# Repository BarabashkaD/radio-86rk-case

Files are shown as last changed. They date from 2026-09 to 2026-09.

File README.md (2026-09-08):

# radio-86rk-case

A 3D model of the [Radio-86RK](https://github.com/BarabashkaD/radio-86rk) as an
assembled machine — the populated board, its 67 keyswitches, the keycaps on top
of them, and the envelope the enclosure will be designed against.

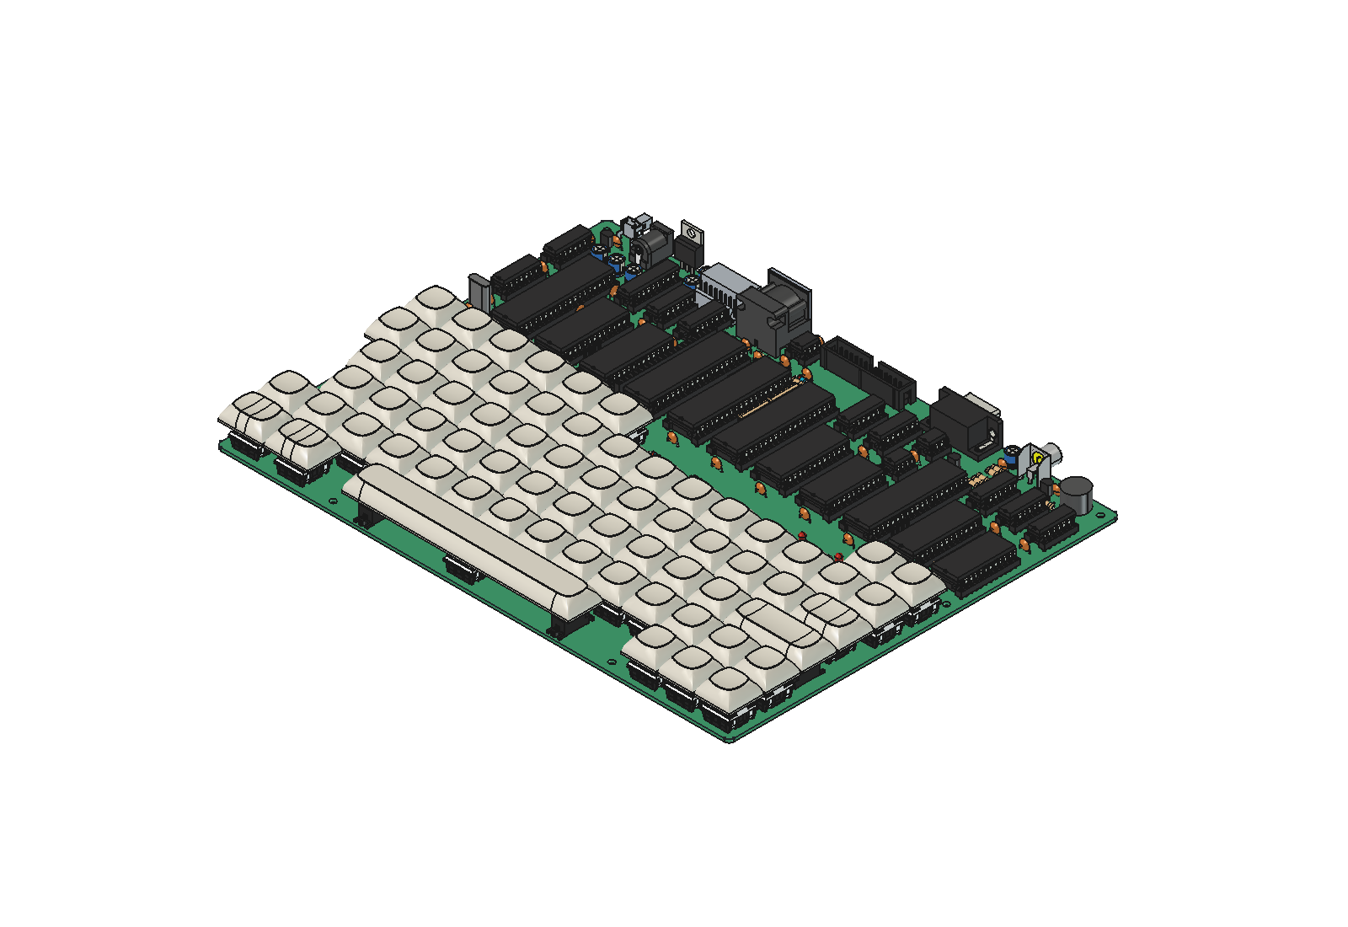
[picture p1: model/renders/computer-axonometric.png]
The assembled Radio-86RK


*The whole machine, built from tracked files in under a second. 251 components,
721 solids, 67 keycaps including the 6.25u spacebar.*

## What this repository is for

The board itself lives in a separate repository and is **read-only from here**.
This one adds everything above the PCB:

| | |
|---|---|
| **The assembled model** | `model/radio86rk-assembly.FCStd` — open it in FreeCAD and you see the machine. No build step, no scripts. |
| **The enclosure interface** | `model/envelope.step` — 67 prisms, one per key, sized to the tallest cap. Everything a case needs *for the keyboard field*; see below for what it does not carry. |
| **The keycaps** | Placed on their switches to a measured seat height, not an estimated one. |
| **A gate that checks all of it** | Eleven checks, from "does the board still have 67 switches" to "do the caps sit where they should". |

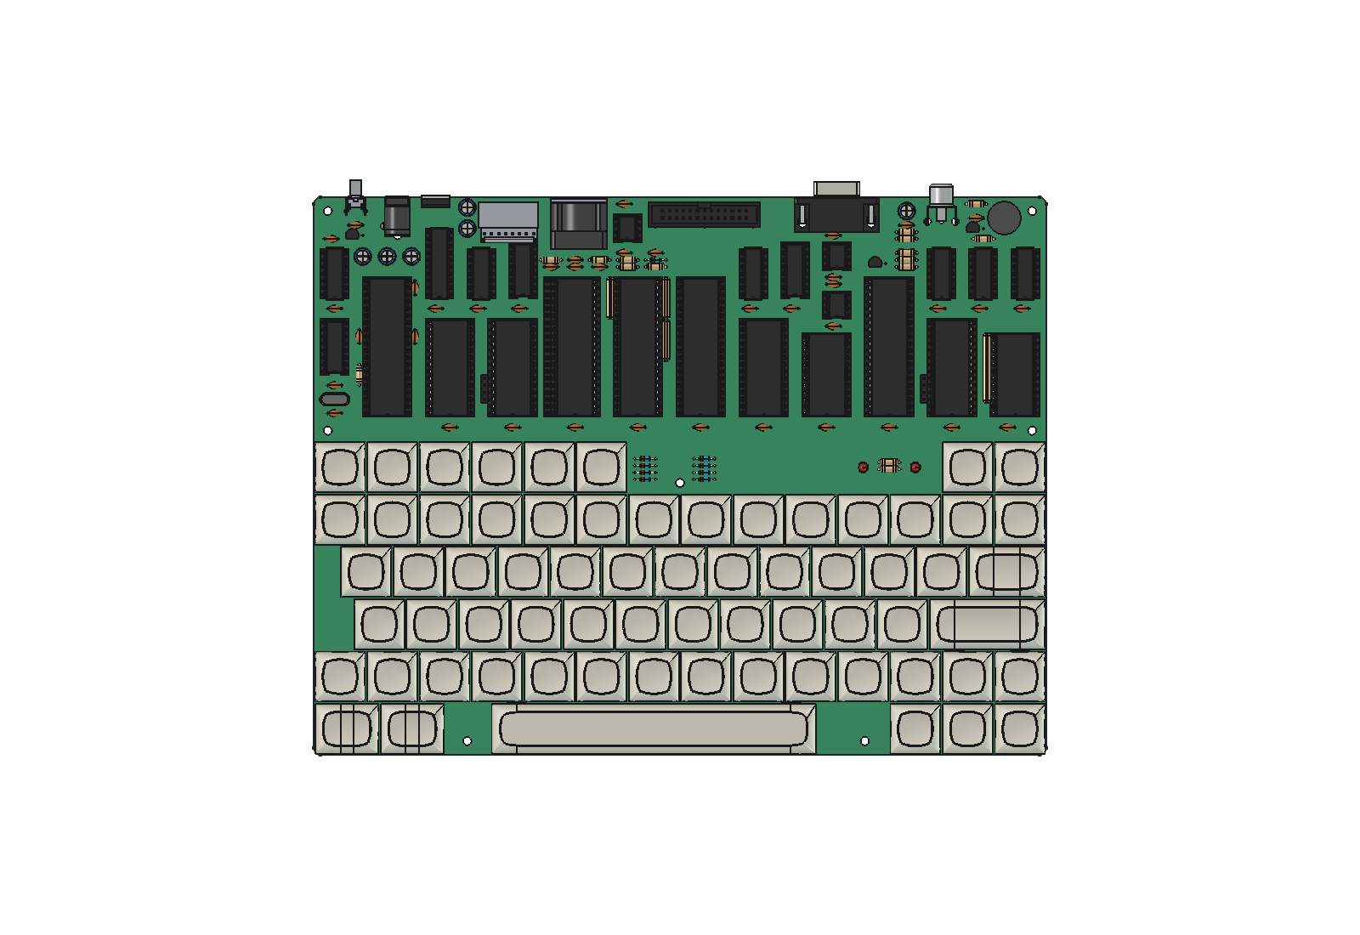
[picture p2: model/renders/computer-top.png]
Top view


## Just looking at it

Open `model/radio86rk-assembly.FCStd` in FreeCAD 1.1.1. That is the whole
instruction. The project is tracked complete — board, components, switches and
caps — so nothing needs building or generating first.

You will get the view above. Both the camera and the visibility state are saved
in the file: construction geometry is hidden, so no grey datum planes obscure
the model, and the stored camera is the isometric the render was shot from.

## Building and checking

Everything runs under FreeCAD's console binary, which is **not on `PATH`**:

    FC=/Applications/FreeCAD.app/Contents/Resources/bin/freecadcmd

    $FC tools/build_caps.py    # place the caps, write model/envelope.step   ~1 s
    $FC tools/verify.py        # the gate: 11 checks                        ~24 s

**In that order.** Four of the eleven checks read what `build_caps.py` writes,
so running the gate on a fresh clone reports `INCOMPLETE` and exit 2 — not
because anything is wrong, but because there is nothing yet to check. Build
first.

Exit codes: `0` pass, `1` a real finding, `2` could not run — never a verdict.
Both always print a `verdict:` line, so you can parse for it. Run one check with
`$FC tools/verify.py C`, or all with no argument.

`build_caps.py` writes `model/envelope.step`, which is tracked. STEP stamps a
timestamp into its header, so `git status` will report it modified after a
rebuild that changed no geometry at all. That is expected — don't commit it
unless the geometry really moved, and `$FC tools/verify.py C D` will tell you
whether it did.

## Designing a case against the envelope

`model/envelope.step` is a compound of exactly **67 rectangular prisms and
nothing else** — 402 planar faces, no board, no fasteners, no annotation. It is
the volume the keys sweep, and it is deliberately that and only that.

It is in **the board's coordinate frame**, which the STEP file itself cannot
tell you, so it is written here:

| | |
|---|---|
| Extent | X `6.675 … 272.725`, Y `−209.225 … −95.575` (266.050 × 113.650 mm) |
| Z | `10.743` (cap base) to `22.743` (cap top), uniform across all 67 |
| Key gap | 0.65 mm — each prism is that much narrower than the 19.05 mm pitch, so neighbours never touch |
| Origin | the board's, shared with `model/radio86rk-assembly.FCStd`. Load both and they line up with no transform |

**What you can design from this file alone**, confirmed by building a plate with
a keyboard cutout against it: the opening outline, the height the case must
clear, the per-key bezel if you want one, and the clearance between keys.

**What it does not carry, and where to get it:** the board outline, mounting
holes, and connector positions are not in here and cannot be derived from it.
Those come from the board — either `model/radio86rk-assembly.FCStd`, which is
in the same frame, or the KiCad project in the `radio-86rk` repository.

One thing is not encoded at all: **key travel**. The Z range is the static
worst case with the caps at rest, not the stroke. If a design needs to clear a
pressed key, that number is a Cherry MX specification, not something this
repository measures.

## Changing the keycaps

The rendered caps and the caps you buy need not match. The envelope is sized
for a sculpted Cherry/OEM profile, so a blank DSA/XDA set or a printed Cyrillic
set will both fit under it.

Swapping the *rendered* profile takes four steps today:

1. Put the new STEP files in `vendor/<profile>/`, one per key size.
2. Point `keycaps.tsv`'s `model_file` column at them — one row per size:
   1u, 1.25u, 1.5u, 2.25u and the 6.25u spacebar.
3. Re-derive the seat height, because a different profile has its stem socket
   at a different depth:

       $FC tools/measure.py seat

   Copy the `seat_dz` it prints into `params.tsv`.
4. Rebuild and check: `$FC tools/build_caps.py && $FC tools/verify.py`

Step 3 is the one that catches people out, and it is why this is four steps
rather than one. See "Known limits" below.

If step 2 points a row at a cap of the wrong width, `build_caps.py` warns and
builds anyway, and the gate refuses it — check B names both widths and the
likely mistake. The build does not adjudicate; the gate does.

## When the board changes

Only then do you need the GUI. KiCadStepUp cannot load under the console
binary, so re-importing the board runs inside a FreeCAD window driven by the
[FreeCAD MCP bridge](https://github.com/blwfish/freecad-mcp):

```python
import sys
sys.path.insert(0, "/path/to/radio-86rk-case")
import tools.import_board as import_board
import_board.rebuild("/path/to/radio-86rk/KiCad/Radio-86RK.kicad_pcb")
```

That takes about 40 s and rewrites `model/placements.json`,
`model/import_log.txt` and `model/radio86rk-assembly.FCStd`. Then rebuild and check
as above.

The `sys.path` line is not boilerplate: a GUI instance does not start in this
repository, and observed working directories have included two unrelated repos.
Set it explicitly rather than reasoning about where it landed.

**After any GUI session, run `git status`.** Closing a FreeCAD window rewrites
the tracked `model/radio86rk-assembly.FCStd` with nothing having called
`save()`. The size of the change varies — 6,289 bytes and 1,594 bytes have both
been observed — so do not go looking for a particular number. Any unexplained
diff on that file is this. `.gitignore` covers the harmless `.FCBak`
that appears beside it and does *not* cover the `.FCStd`. Revert any `.FCStd`
diff you cannot explain. `tools/render.py` closes its document explicitly for
this reason; do the same in any new GUI code.

## Re-shooting the renders

The two images in this README are the visual sign-off record — the one check
the gate cannot run on itself. They need a GUI, because FreeCAD cannot save a
viewport image without one:

```python
import sys
sys.path.insert(0, "/path/to/radio-86rk-case")
import tools.render as render
render.render_all()
```

Both views, 1600×1100, document closed without saving. Keep the resolution —
these files exist to be compared against their predecessors.

## What is tracked, and why

One question decides it: **can this be regenerated headlessly?** If not, it is
tracked, because a checkout without it cannot do most of what this repo is for.

| File | Size | Why |
|---|---|---|
| `model/radio86rk-assembly.FCStd` | 5.6 MB | The assembled model. Recreating it needs a GUI, the KiCadStepUp addon, KiCad's model libraries and the right preferences all lined up; this file survives any of those changing |
| `model/envelope.step` | 397 KB | The enclosure interface — the keyboard field, in board coordinates. A consumer should not have to run FreeCAD to get it |
| `model/placements.json` | 11 KB | Where all 67 switches are. Without it, five checks cannot run |
| `model/import_log.txt` | 154 KB | The import's own record. It is per-process and dies with the FreeCAD instance — unreconstructable afterwards |
| `model/reference-placement.csv` | 11 KB | An independent reading of the board's switch positions, frozen at board revision `4f4c1b5` |
| `model/reference-caps.tsv` | 3 KB | An independent reading of where the caps land, frozen at the same revision. Two checks compare this build against these two files |
| `model/renders/computer-*.png` | 350 KB | The visual sign-off record, 1600×1100. They show the whole machine |

Not tracked, in `.build/` — regenerated in about a second:
`caps/caps.step`, 8.3 MB of placed caps derived entirely from `model/` plus
the vendored profiles.

## Requirements

Every row is checkable by copying the command. Nothing here is on `PATH` — this
is macOS, and both applications bury their binaries inside the bundle.

| What | Want | Run this |
|---|---|---|
| FreeCAD | 1.1.1 | `/Applications/FreeCAD.app/Contents/Resources/bin/freecadcmd --version` |
| KiCadStepUp | 13.1.7 | `grep -E '^___ver___' "$HOME/Library/Application Support/FreeCAD/v1-1/Mod/kicadStepUpMod/kicadStepUptools.py"` |
| FreeCAD MCP bridge | any | `ls ~/.freecad-mcp/freecad_mcp_server.py` — source: [github.com/blwfish/freecad-mcp](https://github.com/blwfish/freecad-mcp) |
| `radio-86rk` checkout | **`4f4c1b5`** | `git -C ../radio-86rk rev-parse --short=7 HEAD` |

The board revision is pinned. One check enforces it, because every tracked file
in `model/` was derived from that revision and silently mixing revisions is the
failure this project most wants to avoid.

**Only the FreeCAD MCP bridge is needed for the GUI steps**, and only when the
board changes or you re-shoot the renders. Building the caps, the envelope and
running the gate need nothing but FreeCAD and a board checkout.

**The KiCadStepUp version is not where you would look for it.** The addon
carries two version markers that disagree: `package.xml` reports `11.09.6`
while `kicadStepUptools.py`'s `___ver___` reports `13.1.7`. The number above is
the second one. Checking the first and concluding your install is broken is a
wasted afternoon.

Two paths are discovered rather than hard-coded, and either can be overridden:
`RADIO86RK_BOARD` (default: the `radio-86rk` checkout beside this one) and
`KSU_MOD` (default: the KiCadStepUp addon in FreeCAD's user directory).

**macOS only, today.** See "Known limits" below.

## Known limits

Written down rather than implied. None of these blocks using the repository as
it stands.

**Swapping caps takes four steps and should take one.** The awkward step is not
busywork: a different profile has its stem socket at a different depth, so the
seat height genuinely has to be re-measured or every cap floats or sinks.
Copying that number by hand is what makes it four steps. A `swap_caps.py` that
measured and wrote `params.tsv` itself would close it — but note that the gate
re-derives `seat_dz` independently on purpose, so a tool writing both the value
and its check would turn that check into a tautology. `params.tsv` also records
*how* each value was derived, and that column must survive.

**macOS only, today.** The FreeCAD binary path and the addon directory are
macOS-shaped, in this file and as defaults in `tools/`. `KSU_MOD` already
overrides the addon path, so that half is solvable by documentation; the
FreeCAD path is hard-coded in every documented command. The honest first step
is stating which paths are platform-specific and giving the Linux and Windows
equivalents — claiming support without a machine to test it on is the kind of
unverified assertion this repository has been bitten by before.

**The frozen references cannot currently be regenerated.** `model/reference-*`
were produced by a second, independent pipeline that has since been removed.
They are recoverable from git history, but nothing in the working tree can
rebuild them. This bites the day the board revision moves: the pinning check
fails first and loudly, and the fix is then either to recover that pipeline or
to retire both cross-checks deliberately — which would drop the gate from
eleven checks to nine and lose the only cross-validation of where the caps
physically land.

**Nothing consumes the envelope yet.** `model/envelope.step` is the interface,
and the enclosure it exists for has not been designed. That is the actual next
piece of work; everything above is housekeeping in front of it. A cold audit
built a trial plate against the envelope and it worked, so the interface is
known to be usable -- but only for the keyboard field. See "Designing a case
against the envelope".

## Provenance and licensing

**This work is GPL-3.0** — see [LICENSE](LICENSE) — matching the Radio-86RK
board repository it reads, so derivative case designs stay open.

**One exception, stated plainly: the vendored keycap models are not covered by
that, and their licence is unknown.** `vendor/dsa/` holds five STEP solids
exported in March 2017 whose headers carry an empty author and an empty
organization; "DSA Keycap Project" is a directory name on someone's drive, not
an attribution. See [vendor/dsa/PROVENANCE.md](vendor/dsa/PROVENANCE.md) for
exactly what the files say about themselves.

This matters beyond `vendor/`: their geometry is baked into
`model/radio86rk-assembly.FCStd` and their measured height sets
`model/envelope.step`, so removing the source files would not remove the
derivatives. If you are a rights holder and object, open an issue — swapping
the profile is one column of `keycaps.tsv` plus a rebuild, and the repository
is built so that is cheap.

The board repository is read-only from here. This project never commits to it,
and one check enforces that.

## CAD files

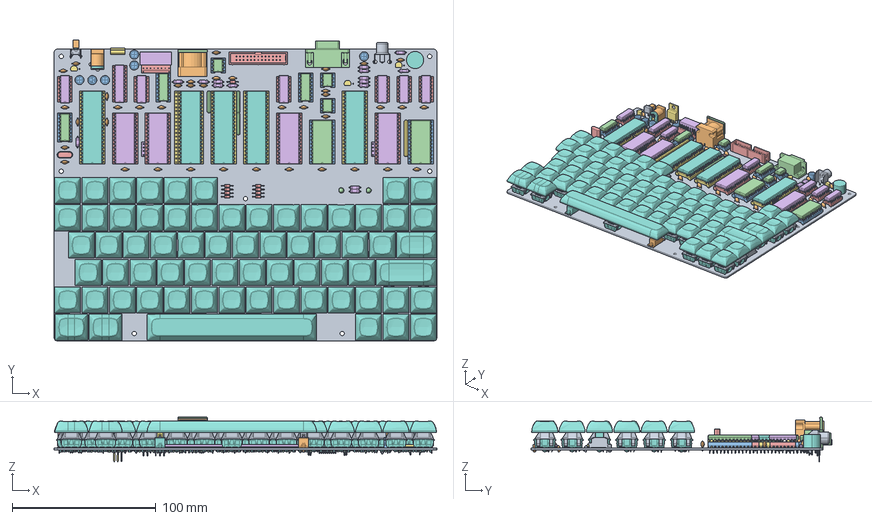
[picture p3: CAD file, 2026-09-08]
model/radio86rk-assembly.FCStd
266.7 x 209.4 x 31.2 mm
Pcb_cd8b
C1_C_Disc_D50mm_W25mm_P500mm_00005e159c5a x 39
C35_CP_Radial_D63mm_P250mm_00005e159e0e x 6
D10_LED_D3.0mm_00005e159e99 x 2
J6_IDC_Header_2x13_P254mm_Vertical_00005e159f24
R1_R_Axial_DIN0207_L63mm_D25mm_P762mm_Horizontal_00005e159f52 x 15
RN1_R_Array_SIP10_00005e15a055
B3F_3152_BUTTON
B3F_3152_BASE
B32_1000
U14_DIP_16_W762mm_Socket_00005e15a2cf x 3
U14_DIP-16_W7.62mm_00005e15a2cf[2] x 3
U17_DIP_14_W762mm_Socket_00005e15a317 x 6
U17_DIP-14_W7.62mm_00005e15a317[2] x 6
U25_TO-220-3_Vertical_00005e15a3bd
SW_Cherry_MX_PCB_cp x 67
SW_Cherry_MX_PCB_cp001 x 67
SW_Cherry_MX_PCB_cp002 x 67
SW_Cherry_MX_PCB_cp003 x 67
SW_Cherry_MX_PCB_cp004 x 67
SW_Cherry_MX_PCB_cp005 x 67
SW_Cherry_MX_PCB_cp006 x 67
Stabilizer_Cherry_MX_2u_cp
Stabilizer_Cherry_MX_2u_cp001
Stabilizer_Cherry_MX_2u_cp002
Stabilizer_Cherry_MX_2u_cp003
Stabilizer_Cherry_MX_2u_cp004
D_DO-35_SOD27_P7.62mm_Horizontal x 9
D_DO-35_SOD27_P7.62mm_Horizontal001 x 9
Stabilizer_Cherry_MX_6_25u_cp
Stabilizer_Cherry_MX_6_25u_cp001
Stabilizer_Cherry_MX_6_25u_cp002
Stabilizer_Cherry_MX_6_25u_cp003
Stabilizer_Cherry_MX_6_25u_cp004
U13_DIP_24_W1524mm_Socket_00005e164864 x 2
U13_DIP_24_W1524mm_00005e164864[2] x 2
U9_DIP_28_W1524mm_Socket_00005e1649df x 4
U9_DIP-28_W15.24mm_00005e1649df[2] x 4
U8_DIP_40_W1524mm_Socket_00005e164a5a x 5
U8_DIP-40_W15.24mm_00005e164a5a[2] x 5
J1_CUI_DEVICES_RCJ-014_00005e164ec3
same sky SDF-80J
same sky SDF-80J001
same sky SDF-80J002
same sky SDF-80J003
same sky SDF-80J004
same sky SDF-80J005
same sky SDF-80J006
same sky SDF-80J007
same sky SDF-80J008
same sky SDF-80J009
RN2_R_Array_SIP6_00005e177f87 x 3
U12_DIP_20_W762mm_Socket_00005e1e1f78
U12_DIP-20_W7.62mm_00005e1e1f78[2]
Q2_TO-92_Inline_Narrow_00005e1e225f x 3
Leads
Leads001
U23_DIP_8_W762mm_Socket_00005e223548 x 3
U23_DIP-8_W7.62mm_00005e223548[2] x 3
KLDX-0202-A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

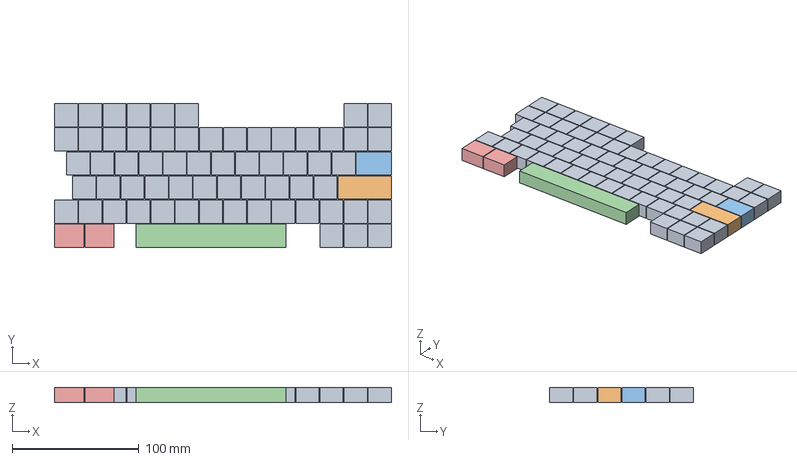
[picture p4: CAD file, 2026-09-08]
model/envelope.step
266.1 x 113.6 x 12.0 mm

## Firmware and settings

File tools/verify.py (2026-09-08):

"""Gate for the ksu-based keycap build (D1.1).

Run every check:     $FC verify.py
Run selected checks: $FC verify.py A A2

Exit 0 pass, 1 a real finding, 2 the gate could not run (never a verdict).

$FC is the FreeCAD console binary. It is NOT on PATH:
    FC=/Applications/FreeCAD.app/Contents/Resources/bin/freecadcmd

Arguments are positional only: FreeCAD swallows flags before Python sees them.
"""
import os
import sys

sys.path.insert(0, os.path.dirname(os.path.abspath(__file__)))
try:
    import board_index                                      # noqa: E402
except Exception as _exc:                                   # noqa: BLE001
    # An unhandled exception at module level exits 0 under freecadcmd, so a
    # gate that cannot even import its own dependency would report success
    # while running no checks at all. Print, flush, then exit 2 -- "could not
    # run", never a verdict.
    print("SKIP: verify could not import board_index: %s: %s"
          % (type(_exc).__name__, _exc))
    sys.stdout.flush()
    sys.exit(2)

REPO = board_index.REPO
BOARD = board_index.BOARD
SUFFIX_UNITS = board_index.SUFFIX_UNITS
EXPECTED_HIST = {"100H": 62, "125H": 2, "150H": 1, "225H": 1, "625H": 1}
EXPECTED_SWITCHES = 67
# Asserted against ksu's measurement in check C, not merely trusted: every
# switch object in the imported document reports this as its ZMax. Without
# that assertion the whole Z chain -- seat_dz, the seat test, check G's Z
# half -- is arithmetic among hand-copied constants that no geometry can
# contradict.
STEM_TOP_Z = 15.443
STEM_TOP_TOL_MM = 0.01
CAP_GAP_MM = 0.65
CAP_MATCH_TOL_MM = 0.01
ROW_TOL_MM = 1.0
SEAT_TOL_MM = 0.10
BOARD_HEAD = "4f4c1b5"
# Two directories, split by one question: can this be regenerated headlessly?
#   MODEL  tracked. Only a GUI FreeCAD session with the ksu addon can produce
#          these, so a checkout without them cannot run most of the gate.
#   CASE   gitignored. Rebuilt in seconds by build_caps.py from MODEL plus the
#          vendored caps -- and STEP files carry a timestamp in their header,
#          so tracking an 8 MB caps.step would churn it on every build for no
#          semantic change.
MODEL = os.path.join(REPO, "model")
CASE = os.path.join(REPO, ".build", "caps")


class Fail(Exception):
    """A real finding: exit 1."""


class Skip(Exception):
    """The gate could not run: exit 2."""


def _howto(script):
    """A runnable command, not a bare name.

    `freecadcmd` is not on PATH on macOS, so a hint that says "run: freecadcmd
    build_caps.py" hands the reader a command that fails with "command not
    found". sys.executable is the interpreter actually running this file, so
    the hint is correct on any machine without hardcoding a path.
    """
    return "%s %s" % (sys.executable, script)


CHECKS = {}


def check(name):
    def deco(fn):
        CHECKS[name] = fn
        return fn
    return deco


@check("A")
def check_layout():
    """The board's layout is what every later step assumes."""
    try:
        index = board_index.build()
    except IOError as exc:
        raise Skip(str(exc))
    if len(index) != EXPECTED_SWITCHES:
        raise Fail("expected %d switches, found %d"
                   % (EXPECTED_SWITCHES, len(index)))
    hist = {}
    for suffix, _units in index.values():
        hist[suffix] = hist.get(suffix, 0) + 1
    if hist != EXPECTED_HIST:
        raise Fail("size histogram changed: %r != %r" % (hist, EXPECTED_HIST))
    for ref, (suffix, units) in index.items():
        if units is None:
            raise Fail("%s has unknown footprint suffix %r" % (ref, suffix))


def obox(shape):
    """Exact bounds.

    Shape.BoundBox over-reports a NURBS solid -- it bounds the control
    polygon, not the surface, and inflated the vendored spacebar by 10.9 mm
    on one side. Costs about 55 ms per solid, so call it once per solid and
    keep the result.
    """
    return shape.optimalBoundingBox()


def load_table(name):
    """Read a TSV, skipping blank lines and # comments."""
    path = os.path.join(REPO, name)
    if not os.path.exists(path):
        raise Skip("no %s" % path)
    if name == "keycaps.tsv":
        header = ["suffix", "units", "model_file", "stab_spacing_mm", "scale_x"]
    else:
        header = ["key", "value", "how_derived"]
    rows = []
    with open(path) as handle:
        for line in handle:
            line = line.rstrip("\n")
            if not line.strip() or line.lstrip().startswith("#"):
                continue
            parts = line.split("\t")
            if len(parts) != len(header):
                raise Fail("%s: expected %d tab-separated fields, got %d: %r"
                           % (name, len(header), len(parts), line))
            rows.append(dict(zip(header, parts)))
    return rows


def cap_shape(suffix):
    """Load one vendored cap, normalised into a Z-up frame with base at Z=0.

    The vendored files are authored Y-up: X and Z carry the 18.2 mm plan
    dimensions centred on the origin, and Y is height with the seating face
    at Y = 0. Rotating +90 degrees about X maps Y to Z. Every cap is authored
    with its MX stem on the model origin, so no re-centring is needed -- and
    re-centring on Shape.BoundBox actively breaks the spacebar.

    A multi-solid cap is fused: DSA 1u ships a shell plus a stem contained
    inside it, and one cap must be one solid downstream.
    """
    import FreeCAD
    import Part
    for row in load_table("keycaps.tsv"):
        if row["suffix"] != suffix:
            continue
        path = os.path.join(REPO, row["model_file"])
        if not os.path.exists(path):
            raise Fail("keycaps.tsv row %r names a missing file: %s"
                       % (suffix, path))
        shape = Part.Shape()
        shape.read(path)
        shape = shape.copy()
        shape.rotate(FreeCAD.Vector(0, 0, 0), FreeCAD.Vector(1, 0, 0), 90)
        scale_x = float(row["scale_x"])
        if scale_x != 1.0:
            matrix = FreeCAD.Matrix()
            matrix.scale(scale_x, 1.0, 1.0)
            shape = shape.transformGeometry(matrix)
        solids = shape.Solids
        if len(solids) > 1:
            fused = solids[0]
            for extra in solids[1:]:
                fused = fused.fuse(extra)
            shape = fused.removeSplitter()
        return shape
    raise Fail("keycaps.tsv has no row for suffix %r" % suffix)


@check("B")
def check_models():
    """Each vendored cap is a solid of the width its row claims."""
    for row in load_table("keycaps.tsv"):
        units = float(row["units"])
        if SUFFIX_UNITS.get(row["suffix"]) != units:
            raise Fail("keycaps.tsv %s says %su, board footprint says %su"
                       % (row["suffix"], units,
                          SUFFIX_UNITS.get(row["suffix"])))
        shape = cap_shape(row["suffix"])
        if len(shape.Solids) < 1:
            raise Fail("%s yields no solids -- a surface-only or mesh import "
                       "would break the D2 booleans" % row["model_file"])
        want = units * 19.05 - CAP_GAP_MM
        got = obox(shape).XLength
        if abs(got - want) > 1.0:
            raise Fail("%s is %.2f mm wide, expected ~%.2f for %su -- wrong "
                       "file in the model_file column?"
                       % (row["model_file"], got, want, units))


@check("A2")
def check_readers_agree():
    """Three readers of one board must agree on which switches exist and
    on how wide each one is.

    This is the SW19 catcher. In D1 a kicad-cli CSV export silently dropped
    that switch -- its legend is `2 "` and the quote was not escaped -- and
    every consumer inherited the loss, so five checks unanimously agreed on
    66 switches.

    The three readers, and why there are three:

      ksu      the GUI import, via placements.json
      parser   board_index.build(), via KiCadStepUp's kicad_parser
      raw      board_index.build_raw(), a stdlib token scan sharing no code

    ksu-vs-parser catches divergence above the parse -- ksu's object
    construction, Label assignment, placement resolution. It cannot catch a
    defect INSIDE kicad_parser, because ksu reaches the board through that
    same module: both would be wrong identically. `raw` closes that gap. It
    is also the only independent source of each switch's SIZE: the suffix
    stored in placements.json is copied from `parser` at join time, so
    comparing those two is a staleness test, not an agreement test.
    """
    import json
    path = os.path.join(MODEL, "placements.json")
    if not os.path.exists(path):
        raise Skip("no %s -- run the ksu build first" % path)
    with open(path) as handle:
        joined = json.load(handle)
    index = board_index.build()
    raw = board_index.build_raw()

    from_ksu = set(joined)
    from_board = set(index)
    from_raw = set(raw)

    # The two board readers first: they share no code, so a disagreement
    # here is a parser defect, and every later comparison would be built on
    # an answer we no longer trust.
    if from_board != from_raw:
        only_parser = sorted(from_board - from_raw)
        only_raw = sorted(from_raw - from_board)
        raise Fail("the two board readers disagree -- only in kicad_parser: "
                   "%s; only in the raw scan: %s"
                   % (only_parser or "none", only_raw or "none"))
    if from_ksu != from_board:
        only_ksu = sorted(from_ksu - from_board)
        only_board = sorted(from_board - from_ksu)
        raise Fail("the two readers disagree -- only in ksu: %s; only in the "
                   "board index: %s" % (only_ksu or "none", only_board or "none"))
    if len(from_ksu) != EXPECTED_SWITCHES:
        raise Fail("both readers agree on %d switches, expected %d"
                   % (len(from_ksu), EXPECTED_SWITCHES))

    for ref in sorted(from_board):
        # Independent: kicad_parser's object model against the raw scan.
        if index[ref][0] != raw[ref][0]:
            raise Fail("%s: kicad_parser reads size %r, the raw scan reads %r"
                       % (ref, index[ref][0], raw[ref][0]))
        # Staleness: what the join FROZE against what the board says now,
        # compared against `raw` so this cannot check a value against the
        # source it was copied from.
        if joined[ref]["suffix"] != raw[ref][0]:
            raise Fail("%s: placements.json says %r, the board says %r -- "
                       "the join is stale, re-run the ksu build"
                       % (ref, joined[ref]["suffix"], raw[ref][0]))


# ksu uses raw KiCad X/Y; D1 is drill-origin relative. Verified on SW3:
#   ksu (15.875, -104.775)  ->  D1 (9.600, -98.500)
# so the mapping is x - 6.275 and y + 6.275. Getting these signs backwards
# makes the comparison fail on a perfectly correct build by 12.55 mm per axis.
DATUM_OFFSET_X = -6.275
DATUM_OFFSET_Y = 6.275
# D1 puts the board BOTTOM on Z=0, ksu puts the board TOP there.
#
# 1.595, NOT the 1.510 that D1's board solid measures. Those are different
# quantities and the difference is real: kicad-cli exports a board solid
# spanning Z 0.000..1.510 while mounting components on a plane 1.595 above
# the same origin. Using the board's thickness as the component offset makes
# the caps appear to disagree by 0.085 mm.
#
# Measured from the SWITCH BODIES, not the caps. Both pipelines placed the
# same SW_Cherry_MX_PCB model from the same board file through completely
# different toolchains, so their stem tops give the frame offset
# independently: D1 17.0375, ksu 15.4425, difference 1.5950 -- identical on
# SW1, SW3 and SW19, at opposite corners of the board.
#
# Deriving this offset from the caps instead would make check G's Z test a
# tautology. Both pipelines seat a cap at (its own stem top - its own socket
# ceiling), so a cap-derived offset would cancel exactly and always pass.
# Taken from the switches, the Z test reduces to "both pipelines measured
# the same socket ceiling" -- which they did independently, in different
# frames, and which is worth asserting.
DATUM_OFFSET_Z = 1.595
XY_TOL_MM = 0.001


@check("A3")
def check_positions_agree():
    """Where each switch SITS, cross-checked against D1's own extraction.

    A2 settles which switches exist and how wide each is; it says nothing
    about position. Check C, which comes later, largely cannot either: the
    caps it measures were BUILT from placements.json, so comparing them back
    to it is self-consistency. C earns its keep on seating, one-to-one
    matching and overlap -- not on absolute XY.

    This is the check that makes absolute position falsifiable, and it uses
    a genuinely separate derivation: D1's placement.csv comes from
    kicad-cli's position export, which shares no code path with ksu. If the
    two agree, the coordinates are right in a way neither pipeline alone can
    establish.

    It runs BEFORE any geometry exists, so a datum error is caught in
    seconds rather than after a full cap build. Check G repeats the
    comparison on the built solids, which is a different assertion: that the
    two pipelines PLACED what they read, not merely that they read the same.
    """
    import csv
    import json
    placements_path = os.path.join(MODEL, "placements.json")
    if not os.path.exists(placements_path):
        raise Skip("no %s -- run the ksu build first" % placements_path)
    # The tracked copy, not D1's gitignored build output. Freezing it does not
    # weaken the cross-check: it was produced by kicad-cli, a toolchain sharing
    # nothing with ksu, and that is where its independence comes from. Freezing
    # does make it a snapshot of one board revision -- which is why check E
    # pins the board's HEAD. If the board moves, E fails first and says so.
    d1_path = os.path.join(MODEL, "reference-placement.csv")
    if not os.path.exists(d1_path):
        raise Skip("no %s -- re-export it with D1's export_mech.py to make "
                   "the cross-check possible" % d1_path)
    with open(placements_path) as handle:
        joined = json.load(handle)

    d1 = {}
    with open(d1_path) as handle:
        for row in csv.DictReader(handle):
            if row["Package"].startswith("CHERRY_PCB_"):
                d1[row["Ref"]] = (float(row["PosX"]), float(row["PosY"]),
                                  float(row["Rot"]))
    if not d1:
        raise Skip("%s holds no CHERRY_PCB_ rows -- it is not a placement "
                   "export of this board" % d1_path)

    if set(joined) != set(d1):
        only_ksu = sorted(set(joined) - set(d1))
        only_d1 = sorted(set(d1) - set(joined))
        raise Fail("the two pipelines disagree on which switches exist -- "
                   "only in ksu: %s; only in D1: %s"
                   % (only_ksu or "none", only_d1 or "none"))

    for ref in sorted(joined):
        entry = joined[ref]
        want_x = entry["x"] + DATUM_OFFSET_X
        want_y = entry["y"] + DATUM_OFFSET_Y
        got_x, got_y, got_rot = d1[ref]
        if abs(want_x - got_x) > XY_TOL_MM or abs(want_y - got_y) > XY_TOL_MM:
            raise Fail("%s sits at (%.4f, %.4f) in ksu, which maps to "
                       "(%.4f, %.4f), but D1 reads (%.4f, %.4f) -- a "
                       "%.4f mm disagreement"
                       % (ref, entry["x"], entry["y"], want_x, want_y,
                          got_x, got_y,
                          max(abs(want_x - got_x), abs(want_y - got_y))))
        if abs(got_rot - entry["rot_deg"]) > 0.001:
            raise Fail("%s is rotated %.3f deg in ksu and %.3f deg in D1"
                       % (ref, entry["rot_deg"], got_rot))
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

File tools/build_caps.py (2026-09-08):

"""Place the keycaps from the placements ksu resolved.

Reads model/placements.json -- produced from the live ksu document joined with
the board index -- and writes the caps and the envelope. No CSV is involved
anywhere in the path.

Outputs go to two places on purpose: model/envelope.step is the deliverable and
is tracked, while .build/caps/caps.step is 8 MB of regenerable geometry
whose STEP header carries a timestamp, so it is not.

Usage: $FC build_caps.py
"""
import json
import os
import sys
import traceback

import FreeCAD
import Part

sys.path.insert(0, os.path.dirname(os.path.abspath(__file__)))
try:
    from verify import CASE, MODEL, cap_shape, load_table  # noqa: E402
except SystemExit as _exc:
    # verify's own import guard calls sys.exit, and SystemExit is NOT an
    # Exception -- so without this clause the build would inherit the gate's
    # "could not run" vocabulary and exit code for what is a build failure.
    print("build failed: verify could not load (exit %s); nothing was "
          "written, the previous caps.step is untouched and now stale"
          % _exc.code)
    sys.stdout.flush()
    sys.exit(1)
except Exception as _exc:                                    # noqa: BLE001
    # Module-level failures exit 0 under freecadcmd. Unguarded, a build that
    # died before it began would report success and leave the PREVIOUS
    # caps.step in place -- which the gate would then validate happily.
    print("build failed: cannot import verify: %s: %s"
          % (type(_exc).__name__, _exc))
    sys.stdout.flush()
    sys.exit(1)


def params():
    out = {}
    for row in load_table("params.tsv"):
        try:
            out[row["key"]] = float(row["value"])
        except ValueError:
            out[row["key"]] = row["value"]
    return out


def _warn_if_wrong_size(suffix, shape, units):
    """Say something when a keycaps.tsv row points at a cap of the wrong width.

    The build used to place whatever the table named and exit 0, so pointing a
    1.25u row at the 1.5u model produced 8 MB of wrong geometry that looked
    like a successful build. The gate catches it -- check B, with a clear
    message -- but only if you run the gate, and the whole point of this
    project is that things should not fail by looking like success.

    A warning rather than an error, deliberately: the gate is the authority on
    whether a build is acceptable, and duplicating its judgement here would
    give two places to disagree. This just refuses to be silent.
    """
    from verify import CAP_GAP_MM, obox
    want = units * 19.05 - CAP_GAP_MM
    got = obox(shape).XLength
    if abs(got - want) > 1.0:
        print("WARNING: the %s row of keycaps.tsv names a cap %.2f mm wide, "
              "but %su should be about %.2f mm. Wrong file in the model_file "
              "column? Building anyway; the gate will refuse this."
              % (suffix, got, units, want))
        sys.stdout.flush()


def placed_caps():
    """Return [(ref, shape)] with every cap moved onto its switch."""
    with open(os.path.join(MODEL, "placements.json")) as handle:
        joined = json.load(handle)
    seat_dz = params()["seat_dz"]
    cache = {}
    out = []
    for ref in sorted(joined, key=lambda r: int(r[2:])):
        entry = joined[ref]
        suffix = entry["suffix"]
        if suffix not in cache:
            cache[suffix] = cap_shape(suffix)
            _warn_if_wrong_size(suffix, cache[suffix], entry["units"])
        # copy before transforming: translate and rotate mutate in place, so
        # without this every placement of a size would share one object.
        shape = cache[suffix].copy()
        shape.translate(FreeCAD.Vector(entry["x"], entry["y"], seat_dz))
        if entry["rot_deg"]:
            shape.rotate(FreeCAD.Vector(entry["x"], entry["y"], 0),
                         FreeCAD.Vector(0, 0, 1), entry["rot_deg"])
        out.append((ref, shape))
    return out


def build_envelope():
    """One prism per key, sized to the tallest cap we allow, as a compound.

    A compound, NOT a fuse: the prisms are CAP_GAP_MM narrower than the pitch
    so neighbours sit 0.65 mm apart and touch nowhere, and the field is sparse
    besides. No boolean merges disjoint solids. One prism per cap is also the
    more useful hand-off -- D2 takes the bounding box for a single well, or
    the individual prisms for a per-key bezel.
    """
    from verify import CAP_GAP_MM
    with open(os.path.join(MODEL, "placements.json")) as handle:
        joined = json.load(handle)
    values = params()
    base_z = values["seat_dz"]
    top_z = values["env_height"]
    prisms = []
    for entry in joined.values():
        width = entry["units"] * 19.05 - CAP_GAP_MM
        depth = 19.05 - CAP_GAP_MM
        prisms.append(Part.makeBox(
            width, depth, top_z - base_z,
            FreeCAD.Vector(entry["x"] - width / 2.0,
                           entry["y"] - depth / 2.0, base_z)))
    return Part.makeCompound(prisms)


def main():
    try:
        os.makedirs(CASE, exist_ok=True)
        caps = placed_caps()
        compound = Part.makeCompound([shape for _ref, shape in caps])
        path = os.path.join(CASE, "caps.step")
        compound.exportStep(path)
        print("caps: %d placed -> %s (%.1f MB)"
              % (len(caps), path, os.path.getsize(path) / 1e6))

        envelope = build_envelope()
        env_path = os.path.join(MODEL, "envelope.step")
        envelope.exportStep(env_path)
        # .Solids rebuilds its list on each access; obox, not BoundBox, even
        # for a printed line -- a number that gets read is a number that gets
        # trusted, and the ban does not have an exception for diagnostics.
        env_solids = envelope.Solids
        env_box = envelope.optimalBoundingBox()
        print("envelope: %d solids, Z %.3f..%.3f -> %s"
              % (len(env_solids), env_box.ZMin, env_box.ZMax, env_path))
        return 0
    except Exception as exc:                                 # noqa: BLE001
        # An unhandled exception under freecadcmd exits 0 and swallows the
        # traceback, so a failed build would report success.
        print("build failed: %s: %s" % (type(exc).__name__, exc))
        traceback.print_exc()
        sys.stdout.flush()
        return 1


def _is_entry_script():
    """True when this file is the script freecadcmd was given."""
    return __name__ == "__main__" or (
        len(sys.argv) > 1
        and os.path.normcase(os.path.realpath(sys.argv[1]))
        == os.path.normcase(os.path.realpath(__file__)))


if _is_entry_script():
    rc = main()
    sys.stdout.flush()
    sys.exit(rc)

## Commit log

2026-09-08 A 3D model of the assembled Radio-86RK
    The board repository stops at the PCB. This one carries the machine: the
    populated board, its 67 keyswitches, the keycaps sitting on them at a measured
    seat height, and the envelope an enclosure will be designed against.
    Open model/radio86rk-assembly.FCStd and you see it. No build step, no scripts,
    nothing to generate first -- the assembled project is tracked complete, because
    recreating it needs a GUI, the KiCadStepUp addon, KiCad's model libraries and
    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
    [envelope.step, keycaps.tsv, params.tsv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]
2026-10-18 Add final v09 enclosure with one consolidated report
    Squash the unpublished enclosure work into one engineering snapshot under case/v09. Include portable FreeCAD models, nine generation modules, STEP/STL parts, views, print metadata and one current REP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
2026-10-19 Add digitally verified v10 enclosure prototype with limitations
    Publish the final saved FreeCAD model, portable generation sources, five canonical STL meshes in seven lossless ZIP volumes, two views, print manifest and one current REPORT.md. Preserve all existing files and the original electronics.
    Nominal CAD, reopen, mesh and documented geometric checks passed. Changed full-case parameter configurations and physical material, fit, fatigue and thermal performance remain unvalidated. STEP is excluded after failed roundtrip checks. See README for 7-Zip extraction and REPORT for the exact validation scope.
